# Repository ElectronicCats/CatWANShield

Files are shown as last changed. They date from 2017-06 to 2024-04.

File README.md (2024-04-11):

# CatWAN Arduino LoRa Shield

<p align="center">
    <a href="https://github.com/ElectronicCats/CatWANShield/wiki">
        
    </a>
</p>

<p align=center>
    <a href="https://electroniccats.com/store/loracatshield/">
        
    </a>
    <a href="https://github.com/ElectronicCats/CatWANShield/wiki">
        
    </a>
</p>

With the CatWAN Arduino LoRa Shield, you will be able to unlock the power of LoRa technology for long-range, low-power communication in an Arduino UNO. Seamlessly integrate your Arduino UNO into LoRaWAN networks for a variety of applications.

This repository contains the KiCad files for a LoRa shield for Arduino Uno and some examples that may help you to get running your LoRa-based applications with the power of an Arduino UNO 

- The folder named "LoRA_PHY_RH" refers to the communication
P2P by the Physical layer of LoRa, in here you can find 2 examples one as the Transmitter (Which also  is capable of receiving information) and the second as the receiver (Which also is capable of transmitting information), both examples work with the [RadioHead](http://www.airspayce.com/mikem/arduino/RadioHead/) library  

- The folder named "LoRA_PHY" refers to the communication
P2P by the Physical layer of LoRa, in here you can find 2 examples one as the Transmitter and the second as the receiver, both examples work with the Official [LoRa](https://github.com/sandeepmistry/arduino-LoRa) library from Arduino.

- The folder named LoRa_WAN refers to the communication by a LoRaWAN network from your device to the internet, by the two methods that exist OTAA and ABP, both examples were created to read a GPS or/and temperature from one analogic sensor attached to the analog input.

Electronic Cats invests time and resources in providing this open-source design, please support Electronic Cats and open-source hardware by purchasing products from Electronic Cats!

Designed by Electronic Cats.

## How to contribute 
 Contributions are welcome! 

Please read the document  [**Contribution Manual**](https://github.com/ElectronicCats/electroniccats-cla/blob/main/electroniccats-contribution-manual.md)  which will show you how to contribute your changes to the project.

✨ Thanks to all our [contributors](https://github.com/ElectronicCats/Cat-Sink/graphs/contributors)! ✨

See [**_Electronic Cats CLA_**](https://github.com/ElectronicCats/electroniccats-cla/blob/main/electroniccats-cla.md) for more information.

See the  [**community code of conduct**](https://github.com/ElectronicCats/electroniccats-cla/blob/main/electroniccats-community-code-of-conduct.md) for a vision of the community we want to build and what we expect from it."			

# License

<a href="https://github.com/ElectronicCats">



</a>

Firmware released under a GNU AGPL v3.0 license. See the LICENSE file for more information.

Hardware released under a CERN Open Hardware Licence v1.2. See the LICENSE_HARDWARE file for more information.

Electronic Cats is a registered trademark, please do not use it if you sell these PCBs.

5 Jul 2018

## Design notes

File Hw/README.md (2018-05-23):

# LoraShield



This repository contains the KiCad files for an LoRa shield for arduino uno and some examples that may help you to get running your LoRa based applications with the power of an Arduino UNO 

- The folder named "LoRA_PHY" refer to the communication
P2P by the Physical layer of LoRa,in here you can find 2 examples one as the Transmitter (Which also  is capable of receive information) and the second as the receiver (Which also is capable of transmit e information), 

- The folder named LoRa_WAN refer to the communication by a LoRaWAN network from your device to internet, by the two methods that exist OTAA and ABP, both examples were created to read an GPS or/and temperature from one analogic sensor attached to the analog input.

Electronic Cats invests time and resources providing this open source design, please support Electronic Cats and open-source hardware by purchasing products from Electronic Cats!

Designed by Electronic Cats.

Firmware released under an GNU AGPL v3.0 license. See the LICENSE file for more information.

Hardware released under an CERN Open Hardware Licence v1.2. See the LICENSE_HARDWARE file for more information.

Electronic Cats is a registered trademark, please do not use if you sell these PCBs.

15 Nov 2017

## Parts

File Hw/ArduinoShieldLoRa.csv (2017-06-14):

Reference | Value | Footprint | Datasheet | MP | Package | Availability | MF | Description | #manf
U2 | 74HC4050D | ArduinoShieldLoRa:74HC4050D | 0.45 USD | 74HC4050D | SOIC-16 NXP Semiconductors | Good | NXP Semiconductors | Hex high-to-low level shifter 74HC4050D | 74HC4050D,653
U1 | RFM95 | ArduinoShieldLoRa:RFM95
A1 | ANT | ArduinoShieldLoRa:SMA_EDGELAUNCH_UFL
U3 | AP2112K-3.3 | ArduinoShieldLoRa:AP2112K-3.3 |  |  |  |  |  |  | AP2112K-3.3TRG1
R1 | 100K | Resistors_SMD:R_0603_HandSoldering
C1 | 10uF | Capacitors_SMD:C_0603_HandSoldering |  |  |  |  |  |  | GRM188C80G106KE47J
C2 | 0.1uF | Capacitors_SMD:C_0603_HandSoldering |  |  |  |  |  |  | 0201ZD104KAT2A
C3 | 10uF | Capacitors_SMD:C_0603_HandSoldering |  |  |  |  |  |  | GRM188C80G106KE47J
J1 | CONN_01X03 | Pin_Headers:Pin_Header_Straight_1x03_Pitch2.54mm

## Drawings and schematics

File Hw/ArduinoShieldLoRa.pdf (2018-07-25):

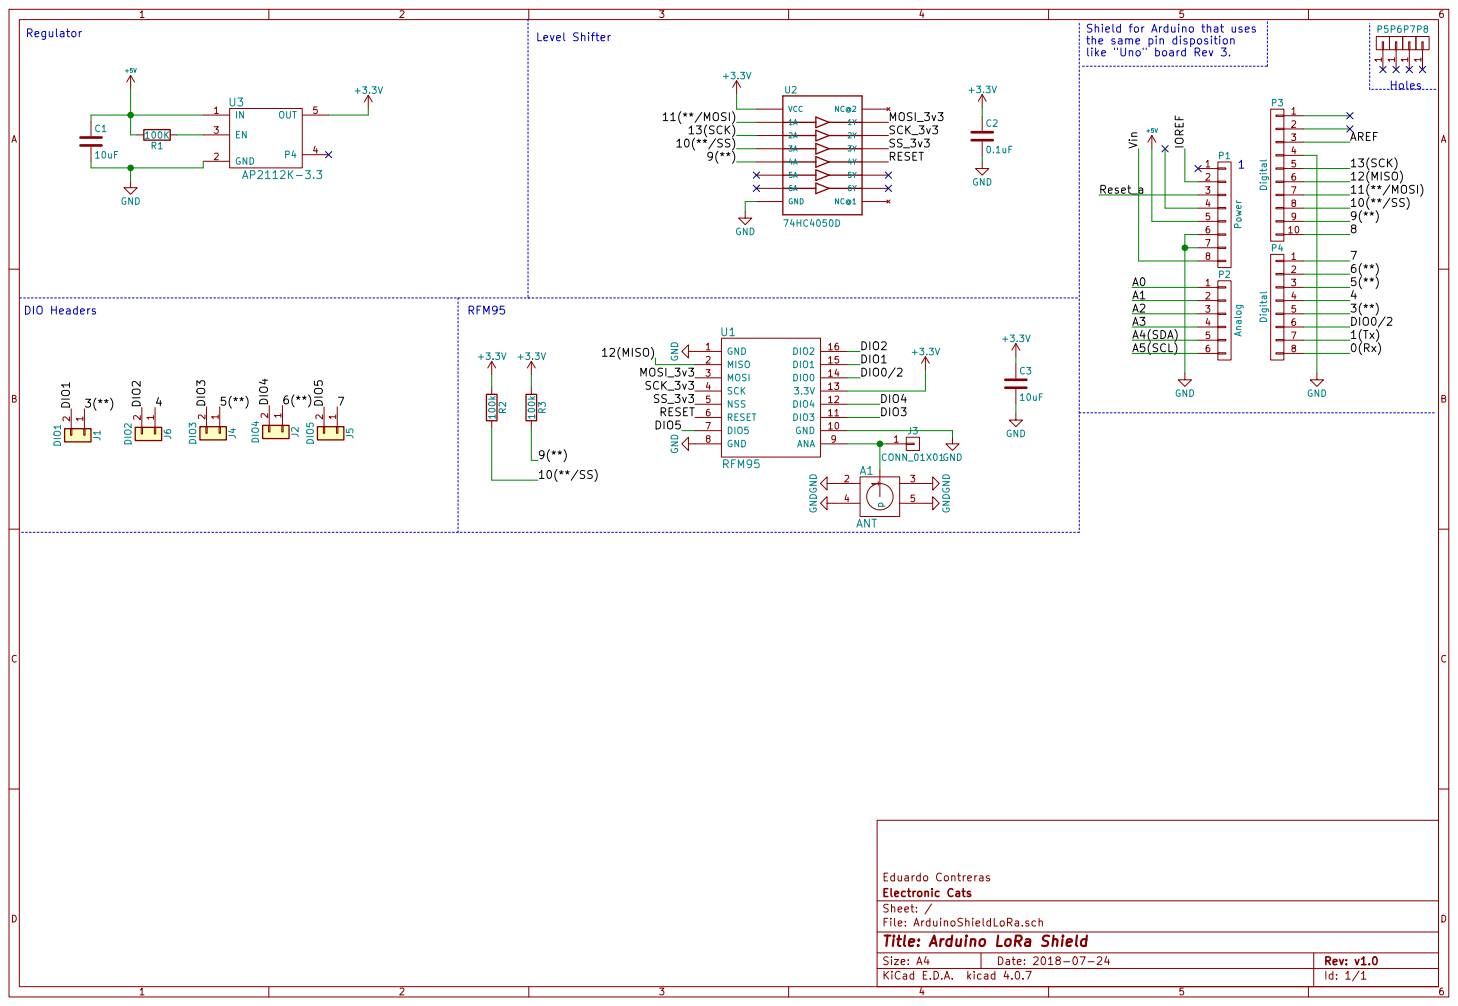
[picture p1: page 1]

the same pin disposition
like "Uno" board Rev 3. 1
10 P3 Digital1
8 P1 Power

Id: 1/1 Title: Arduino LoRa Shield

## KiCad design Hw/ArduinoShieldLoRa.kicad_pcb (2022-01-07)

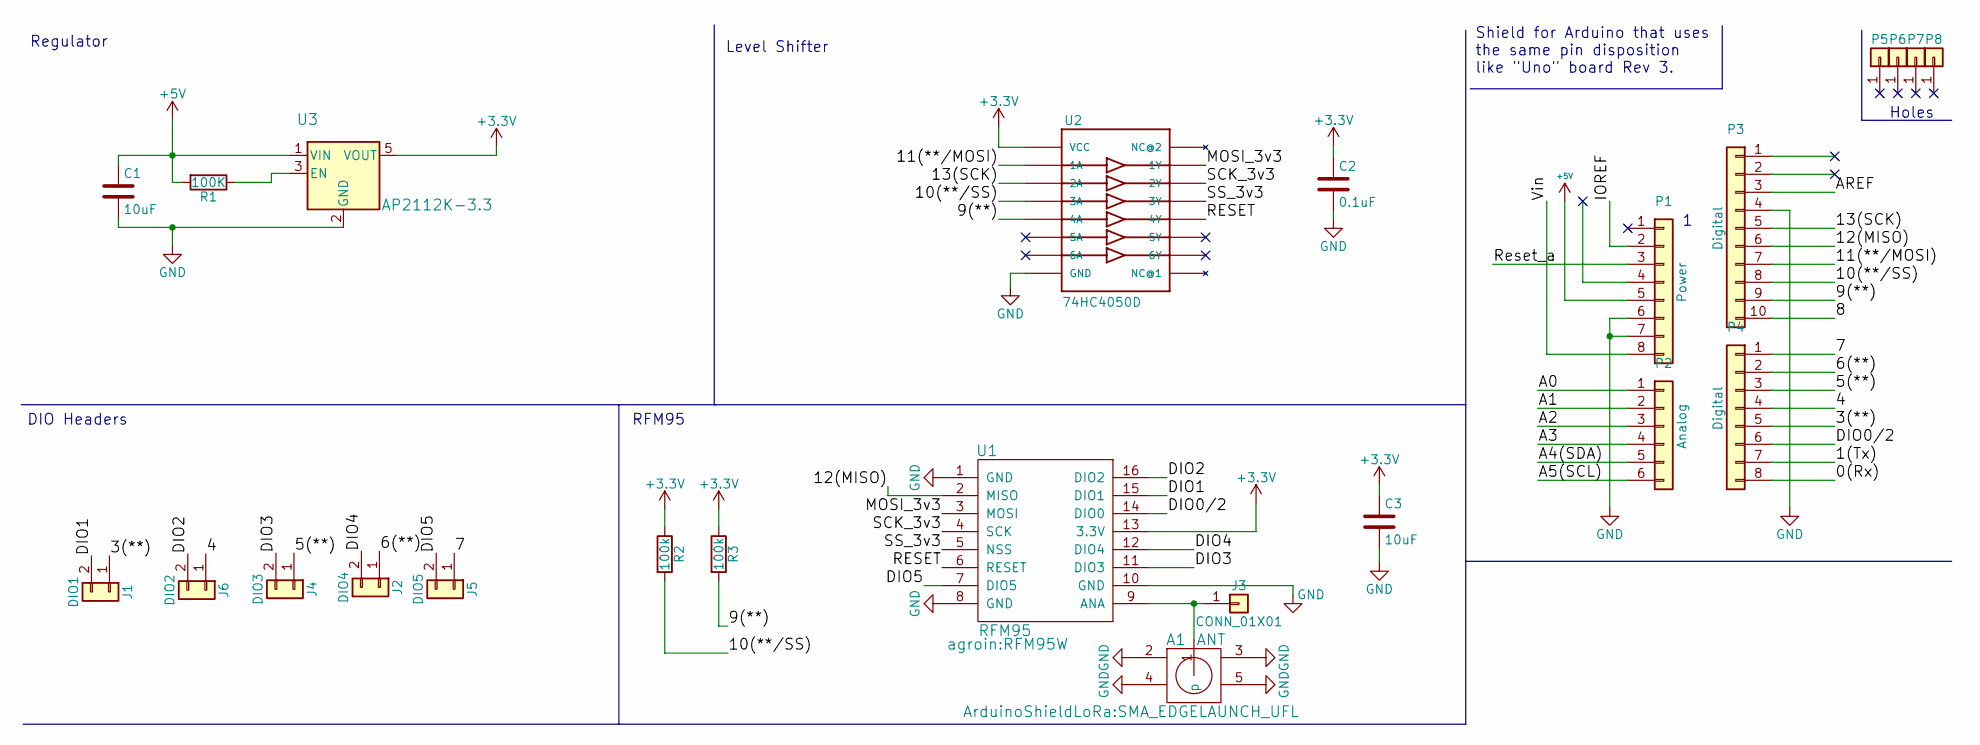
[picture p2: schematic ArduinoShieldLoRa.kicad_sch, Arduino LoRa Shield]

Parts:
A1: ANT; SMA_EDGELAUNCH_UFL
C1, C3: 10uF; C_0805_HandSoldering
C2: 0.1uF; C_0805_HandSoldering
J1: DIO1; Pin_Header_Straight_1x02_Pitch2.54mm
J2: DIO4; Pin_Header_Straight_1x02_Pitch2.54mm
J3: CONN_01X01; SolderWirePad_single_0-8mmDrill
J4: DIO3; Pin_Header_Straight_1x02_Pitch2.54mm
J5: DIO5; Pin_Header_Straight_1x02_Pitch2.54mm
J6: DIO2; Pin_Header_Straight_1x02_Pitch2.54mm
P1: Power; Socket_Strip_Arduino_1x08
P2: Analog; Socket_Strip_Arduino_1x06
P3: Digital; Socket_Strip_Arduino_1x10
P4: Digital; Socket_Strip_Arduino_1x08
P5, P6, P7, P8: CONN_01X01; Arduino_1pin
R1: 100K; R_0805_HandSoldering
R2, R3: 100k; R_0805_HandSoldering
U1: RFM95; RFM95W
U2: 74HC4050D; SO16
U3: AP2112K-3.3; SOT-23-5

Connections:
+3V3: C2.1, C3.1, R2.1, R3.1, U1.13 (3.3V), U2.1 (VCC), U3.5 (VOUT)
/0(Rx): P4.8
/1(Tx): P4.7
/3(**): J1.1, P4.5
/4: J6.1, P4.4
/5(**): J4.1, P4.3
/6(**): J2.1, P4.2
/7: J5.1, P4.1
/8: P3.10
/9(**): P3.9, R3.2, U2.9 (4A)
/10(**/SS): P3.8, R2.2, U2.7 (3A)
/11(**/MOSI): P3.7, U2.3 (1A)
/12(MISO): P3.6, U1.2 (MISO)
/13(SCK): P3.5, U2.5 (2A)
/A0: P2.1
/A1: P2.2
/A2: P2.3
/A3: P2.4
/A4(SDA): P2.5
/A5(SCL): P2.6
/AREF: P3.3
/DIO0/2: P4.6, U1.14 (DIO0)
/DIO1: J1.2, U1.15 (DIO1)
/DIO2: J6.2, U1.16 (DIO2)
/DIO3: J4.2, U1.11 (DIO3)
/DIO4: J2.2, U1.12 (DIO4)
/DIO5: J5.2, U1.7 (DIO5)
/IOREF: P1.2
/MOSI_3v3: U1.3 (MOSI), U2.2 (1Y)
/RESET: U1.6 (RESET), U2.10 (4Y)
/Reset_a: P1.3
/SCK_3v3: U1.4 (SCK), U2.4 (2Y)
/SS_3v3: U1.5 (NSS), U2.6 (3Y)
/Vin: P1.8
GND: A1.2, A1.3, A1.4, A1.5, C1.2, C2.2, C3.2, P1.6, P1.7, P3.4, U1.1 (GND), U1.8 (GND), U1.10 (GND), U2.8 (GND), U3.2 (GND)
unnamed: A1.1 (p), J3.1, U1.9 (ANA)
unnamed: R1.1, U3.3 (EN)

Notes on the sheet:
DIO Headers
RFM95
Shield for Arduino that uses the same pin disposition like "Uno" board Rev 3.
Level Shifter
Holes
Regulator

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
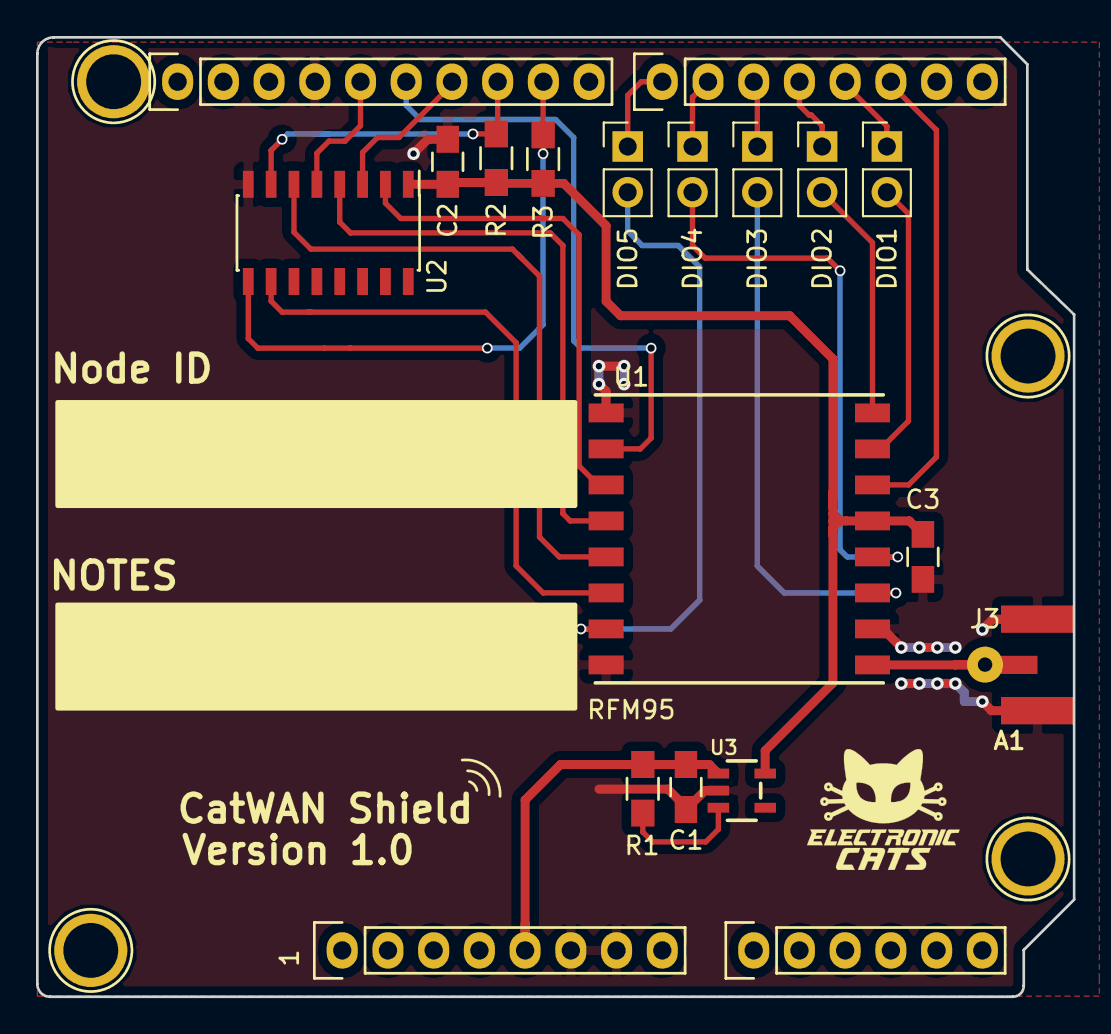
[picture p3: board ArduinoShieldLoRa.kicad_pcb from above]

Board: 2 copper layers, 57.6 x 53.3 mm, 25 parts (1 on the bottom side), 25 nets.

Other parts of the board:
svg2mod: electronic; titule_electronic_med

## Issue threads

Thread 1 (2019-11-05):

Consulta rango bajo shield arduino

sabas1080, 2019-11-05:
Buen dia como le comente por llamada tengo problema con el rango de transmisión de mi shield para arduino. Envio fotos de mi conexion, las antenas que utilizo y la potencia.

Las conexiones que tiene el arduino son solo 4 botones de input y la pantalla lcd.

La potencia que tengo es a una distancia de unos 20cm.

Estoy usando el codigo del repositorio de LoRa, LoRaDuplex.

De antemanos agradezco la ayuda
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

sabas1080, 2019-11-05:
Christian ¿Las antenas usadas son a 915Mhz?

wero1414, 2019-11-05:
No es nada comun que sean 20 cm incluso teniendo los transmisores sin antena solo con conector SMA (Cosa que no debes hacer), a mi me parece ser un problema de soldado del pin del RFM95 al conector de antena, habra que checar continuidad del pin de salida de RF a el pin interno del conector SMA

wero1414, 2019-11-05:
Otra cosa, el pin DIO0 del radio esta conectado al pin 2 del Arduino uno para la interrupcion de recepcion de datos o bien el termino de transmisión, al ver las fotos creo que estas usando el pin 2 con un boton externo, por lo tanto puede que si tienes una configuración pull-down en tu boton puedes estar inyectando voltaje al pin DIO0 que puede estar haciendo que el radio funcione incorrectamente.

christianacajabon, 2019-11-05:
Fijate que del ejemplo utilizado prescindi del siguiente codigo que dice que es opcional, ya que con este comando me daba un error de inicializar el Lora. Antes incluso de configurar botones, pantalla y modificar mis mensajes.

  // override the default CS, reset, and IRQ pins (optional)
  LoRa.setPins(csPin, resetPin, irqPin);// set CS, reset, IRQ pin

wero1414, 2019-11-05:
Ese sirve por si usas el shield en otra tarjeta que no sea arduino uno, pero dejare el arduino uno por default

christianacajabon, 2019-11-05:
Creo que si es un shield el problema, probe con un tercero y ya funciona bien. Como podria solucionar el problema del shield? O tiene alguna garantia?

wero1414, 2019-11-05:
Para poder solucionarlo hay que ver que el pin de RF este bien soldado, te podemos ofrecer un descuento en futuras compras por las molestias en tu producto.

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

Closed 2022-08-22.

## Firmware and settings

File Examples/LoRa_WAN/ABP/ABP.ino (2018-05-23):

/*******************************************************************************
  Created by Eduardo Contreras @ Electronic Cats 2016
  Based on Copyright (c) 2015 Thomas Telkamp and Matthijs Kooijman
  PLEASE REFER TO THIS LMIC LIBRARY https://github.com/things-nyc/arduino-lmic
  
  LoRaShield
  In this example you can send GPS information (Compatible with the L80)
  or a temperature read by the ADC  
  Example
 *******************************************************************************/

#include <lmic.h>
#include <hal/hal.h>
#include <SPI.h>
#include <math.h>
#include <SoftwareSerial.h>

//#define _USE_GPS_
#define _USE_TEMP_
//#define _USE_ULTRASONIC_

#ifdef _USE_GPS_
#include <TinyGPS++.h>
SoftwareSerial ss(6, 5);
TinyGPSPlus gps;
double gps_lat = 0;
double gps_lng = 0;
double gps_alt = 0;
bool gpsEncoded = false;
#endif

#ifdef _USE_ULTRASONIC_
const int trigPin = 7;
const int echoPin = 8;
#endif


#define debugSerial Serial

unsigned long previousMillis = 0;


static const PROGMEM u1_t NWKSKEY[16] ={0x98,0xBB,0x8C,0x22,0xFC,0x0D,0x1F,0xB5,0xEF,0x8E,0xA2,0x90,0x76,0xFB,0xCF,0xA7};
static const u1_t PROGMEM APPSKEY[16] ={0xA4,0x98,0xF9,0x32,0xDF,0x71,0xDC,0x0A,0xB2,0xA6,0x15,0x77,0xC4,0xC4,0xCC,0xE7};
static const u4_t DEVADDR =0x077ce77f;


void os_getArtEui (u1_t* buf) { }
void os_getDevEui (u1_t* buf) { }
void os_getDevKey (u1_t* buf) { }

// We will be using Cayenne Payload Format
// For one sensor,
// the general format is channel | type | payload
// payload size depends on type
// here we are using temperature, GPS and customised PM25,
// temperature - 2, GPS - 9, PM25 - 2

static osjob_t sendjob;

// Schedule TX every this many seconds (might become longer due to duty
// cycle limitations).
const unsigned TX_INTERVAL = 20;

// Pin mapping for RFM9X
const lmic_pinmap lmic_pins = {
    .nss = 10,
    .rxtx = LMIC_UNUSED_PIN,
    .rst = 9,
    .dio = {2, 3, 4},
};

void debug_char(u1_t b) {
  debugSerial.write(b);
}

void debug_hex (u1_t b) {
  debug_char("0123456789ABCDEF"[b >> 4]);
  debug_char("0123456789ABCDEF"[b & 0xF]);
}

void debug_buf (const u1_t* buf, u2_t len) {
  while (len--) {
    debug_hex(*buf++);
    debug_char(' ');
  }
  debug_char('\r');
  debug_char('\n');
}

void onEvent (ev_t ev) {
  switch (ev) {
    case EV_TXCOMPLETE:

      // indicating radio TX complete
      digitalWrite(A1, LOW);

      debugSerial.println(F("[LMIC] Radio TX complete (included RX windows)"));
      if (LMIC.txrxFlags & TXRX_ACK)
        debugSerial.println(F("[LMIC] Received ack"));
      if (LMIC.dataLen) {
        debugSerial.print(F("[LMIC] Received "));
        debugSerial.print(LMIC.dataLen);
        debugSerial.println(F(" bytes of payload"));
        debug_buf(LMIC.frame + LMIC.dataBeg, LMIC.dataLen);
      }
      break;

    default:
      debugSerial.println(F("[LMIC] Unknown event"));
      break;
  }
}

void do_send(osjob_t* j, uint8_t *mydata1, uint16_t len) {
  // Check if there is not a current TX/RX job running
  if (LMIC.opmode & OP_TXRXPEND) {
    debugSerial.println(F("[LMIC] OP_TXRXPEND, not sending"));
  } else {
    // Prepare upstream data transmission at the next possible time
    LMIC_setTxData2(1, mydata1, len, 0);
  }
}



void setup() {
  debugSerial.begin(115200);
  debugSerial.println(F("[INFO] LoRa Demo Node 1 Demonstration"));

  // start GPS object
  #ifdef _USE_GPS_
  ss.begin(9600);
  #endif

  #ifdef _USE_ULTRASONIC_
  pinMode(trigPin, OUTPUT); // Sets the trigPin as an Output
  pinMode(echoPin, INPUT); // Sets the echoPin as an Input
  #endif

  os_init();
  LMIC_reset();

  uint8_t appskey[sizeof(APPSKEY)];
  uint8_t nwkskey[sizeof(NWKSKEY)];
  memcpy_P(appskey, APPSKEY, sizeof(APPSKEY));
  memcpy_P(nwkskey, NWKSKEY, sizeof(NWKSKEY));

  LMIC_setSession (0x1, DEVADDR, nwkskey, appskey);
  //LMIC_selectSubBand(2);
  for (int channel=0; channel<72; ++channel) {
      LMIC_disableChannel(channel);
    }
  //SF TTN
  /*
      LMIC_enableChannel(8);
      LMIC_enableChannel(9);
      LMIC_enableChannel(10);  //904.3Mhz
      LMIC_enableChannel(11);
      LMIC_enableChannel(12);
      LMIC_enableChannel(13);
      LMIC_enableChannel(14);
      LMIC_enableChannel(15);
      LMIC_enableChannel(65); 
   */
  //Home
    
      LMIC_enableChannel(48);
      LMIC_enableChannel(49);
      LMIC_enableChannel(50);
      LMIC_enableChannel(51);
      LMIC_enableChannel(52);
      LMIC_enableChannel(53);
      LMIC_enableChannel(54);
      LMIC_enableChannel(55);
      LMIC_enableChannel(70);
  
  LMIC_setLinkCheckMode(0);
  LMIC_setAdrMode(false);
  LMIC_setDrTxpow(DR_SF7, 14); //SF7

  previousMillis = millis();

}

void loop() {

  if (millis() > previousMillis + TX_INTERVAL * 1000) { //Start Job at every TX_INTERVAL*1000

    getInfoAndSend();
    previousMillis = millis();
  }

  os_runloop_once();
}

void getInfoAndSend() {

  uint8_t len=0;   //Bug of len

  uint8_t mydata[255];
  uint8_t cnt = 0;
  uint8_t ch = 0;
  debugSerial.println(F("[INFO] Collecting info"));
 
  #ifdef _USE_ULTRASONIC_
  len+=4;
  uint16_t distance = readDistance(); 
  uint8_t Percent = map(distance,1,150,100,0);
  debugSerial.print(F("[INFO] Distance:")); debugSerial.println(distance);
  debugSerial.print(F("[INFO] Distance (%):")); debugSerial.println(Percent);  
  mydata[cnt++] = 0x01;
  mydata[cnt++] = (distance>>8)&0xFF;
  mydata[cnt++] = distance&0xFF;
  mydata[cnt++] = Percent;
  #endif
  
  #ifdef _USE_TEMP_// Temperature
  len += 4; // temperature
  //float temp = readTemperature();
  float temp = 10;
  debugSerial.print(F("[INFO] Temperature:")); debugSerial.println(temp);
  int val = round(temp * 10);
  mydata[cnt++] = ch;
  mydata[cnt++] = 0x67;
  mydata[cnt++] = highByte(val);
  mydata[cnt++] = lowByte(val);
  #endif
  // GPS
  #ifdef _USE_GPS_// Temperature
  len += 11; // GPS
  if (gpsEncoded) {
    digitalWrite(A0, LOW);
    debugSerial.println(F("[INFO] Collecting GPS info"));
    debugSerial.print(F("[INFO] Lat:")); debugSerial.println(String(gps_lat, 6));
    debugSerial.print(F("[INFO] Lng:")); debugSerial.println(String(gps_lng, 6));
    debugSerial.print(F("[INFO] Alt:")); debugSerial.println(gps_alt);
    long lat = round(gps_lat * 10000);
    long lng = round(gps_lng * -10000);
    long alt = round(gps_alt * 100);
    ch = ch + 1;
    mydata[cnt++] = ch;
    mydata[cnt++] = 0x88;
    mydata[cnt++] = lat >> 16;
    mydata[cnt++] = lat >> 8;
    mydata[cnt++] = lat;
    mydata[cnt++] = lng >> 16;
    mydata[cnt++] = lng >> 8;
    mydata[cnt++] = lng;
    mydata[cnt++] = alt >> 16;
    mydata[cnt++] = alt >> 8;
    mydata[cnt++] = alt;
  }
  else{
    digitalWrite(A0, HIGH);
    debugSerial.println(F("[INFO] Collecting GPS info"));
    debugSerial.print(F("[INFO] Lat:")); debugSerial.println(String(21.900932, 6));
    debugSerial.print(F("[INFO] Lng:")); debugSerial.println(String(102.316399, 6));
    debugSerial.print(F("[INFO] Alt:")); debugSerial.println(1900);
    long lat = round(1900 * 10000);
    long lng = round(21.900932 * -10000);
    long alt = round(102.316399 * 100);
    ch = ch + 1;
    mydata[cnt++] = ch;
    mydata[cnt++] = 0x88;
    mydata[cnt++] = lat >> 16;
    mydata[cnt++] = lat >> 8;
    mydata[cnt++] = lat;
    mydata[cnt++] = lng >> 16;
    mydata[cnt++] = lng >> 8;
    mydata[cnt++] = lng;
    mydata[cnt++] = alt >> 16;
    mydata[cnt++] = alt >> 8;
    mydata[cnt++] = alt;
  }
  #endif

  

  if (cnt == len) {
    debugSerial.println(F("[LMIC] Start Radio TX"));

    // indicating start radio TX
    digitalWrite(A1, HIGH);
    for(int i;i<sizeof(mydata);i++){
    debugSerial.print(mydata[i]);
    }
    debugSerial.println();
    do_send(&sendjob, mydata, sizeof(mydata));
  }
  else
    debugSerial.println(F("[ERROR] Data stack incorrect"));
}

#ifdef _USE_TEMP_// Temperature
float readTemperature() {

  int a = analogRead(A0);
  float R = 1023.0 / ((float)a) - 1.0;
  R = 100000.0 * R;

  float temperature = 1.0 / (log(R / 100000.0) / 4275 + 1 / 298.15) - 273.15; //convert to temperature via datasheet ;

  return temperature;

}
#endif


#ifdef _USE_ULTRASONIC_
uint16_t readDistance(void){
   long duration;
    uint16_t distance;
    digitalWrite(trigPin, LOW);
    delayMicroseconds(2);
    // Sets the trigPin on HIGH state for 10 micro seconds
    digitalWrite(trigPin, HIGH);
    delayMicroseconds(10);
    digitalWrite(trigPin, LOW);
    // Reads the echoPin, returns the sound wave travel time in microseconds
    duration = pulseIn(echoPin, HIGH);
    // Calculating the distance
    distance= duration*0.034/2;
    return distance;
}
#endif
    
#ifdef _USE_GPS_
void GPS_loop() {
  if (!ss.isListening()) {
    ss.listen();
  }
  while (ss.available() > 0) {
    if (gps.encode(ss.read())) {

      if (gps.location.isValid() && gps.altitude.isValid()) {

        // indicating GPS is successfully obtained
        gpsEncoded = true;

        // update the locations
        gps_lat = gps.location.lat();
        gps_lng = gps.location.lng();
        gps_alt = gps.altitude.meters();
      }
    }
  }
}
#endif

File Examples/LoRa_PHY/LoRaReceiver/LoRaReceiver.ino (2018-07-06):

#include <SPI.h>
#include <LoRa.h>

void setup() {
  Serial.begin(9600);
  while (!Serial);
  
  LoRa.setPins(10, 9, 2);
  
  Serial.println("LoRa Receiver");

  if (!LoRa.begin(915E6)) {
    Serial.println("Starting LoRa failed!");
    while (1);
  }
}

void loop() {
  // try to parse packet
  int packetSize = LoRa.parsePacket();
  if (packetSize) {
    // received a packet
    Serial.print("Received packet '");

    // read packet
    while (LoRa.available()) {
      Serial.print((char)LoRa.read());
    }

    // print RSSI of packet
    Serial.print("' with RSSI ");
    Serial.println(LoRa.packetRssi());
  }
}

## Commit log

2017-06-14 Add project
    [ArduinoShieldLoRa.csv, ArduinoShieldLoRa.kicad_pcb, ArduinoShieldLoRa.sch]
2017-06-14 Add resistors
    [ArduinoShieldLoRa.kicad_pcb, ArduinoShieldLoRa.sch]
2017-06-14 add pin for cable as antenna
    [ArduinoShieldLoRa.kicad_pcb, ArduinoShieldLoRa.sch]
2017-06-14 Added logos
    [ArduinoShieldLoRa.kicad_pcb]
2017-06-14 Gerber config
    [ArduinoShieldLoRa.kicad_pcb]
2017-11-15 add gitignore
    [ArduinoShieldLoRa.kicad_pcb, ArduinoShieldLoRa.sch]
2018-05-23 update library
    [ArduinoShieldLoRa.sch]
2018-07-06 Update folder for KiCad project
    [ArduinoShieldLoRa.csv, ArduinoShieldLoRa.sch]
2018-07-06 Add Arduino LoRa Library
2018-07-25 Manita de gato CatWAN shield
    [ArduinoShieldLoRa.kicad_pcb, ArduinoShieldLoRa.sch]
2018-07-25 Update sch
    [ArduinoShieldLoRa.sch]
2018-07-25 data place
    [ArduinoShieldLoRa.kicad_pcb]
2022-01-07 Update to KiCad 6.0
    [ArduinoShieldLoRa-2022-01-07-15-07-12.sch, ArduinoShieldLoRa-2022-01-07-15-15-21.sch, ArduinoShieldLoRa-2022-01-07-15-15-57.sch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]
